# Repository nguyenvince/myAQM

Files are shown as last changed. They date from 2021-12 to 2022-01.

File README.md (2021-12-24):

# myAQM - A Personal Air Quality Monitor with Apple Watch Interface
This is the source code and documentation for **myAQM**, a personal air quality monitor (AQM) system that consists of a portable monitor that transmits measurements to an iOS/watchOS application user interface. This source code includes:
### 1. [Portable air quality monitor (completed)](/Portable%20air%20quality%20monitor)
- Fabrication guide (Refer to README.md)
- Arduino project
- Hardware fabrication files (3D-print and custom PCB files)
  
### 2. iOS/watchOS application (currently under-development)
XCode project

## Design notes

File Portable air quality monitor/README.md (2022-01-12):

# Open-source portable air quality monitor
```
Topics covered:  
Arduino IDE, ESP32, BLE, 3D-printing, PCB-fabricating 
```
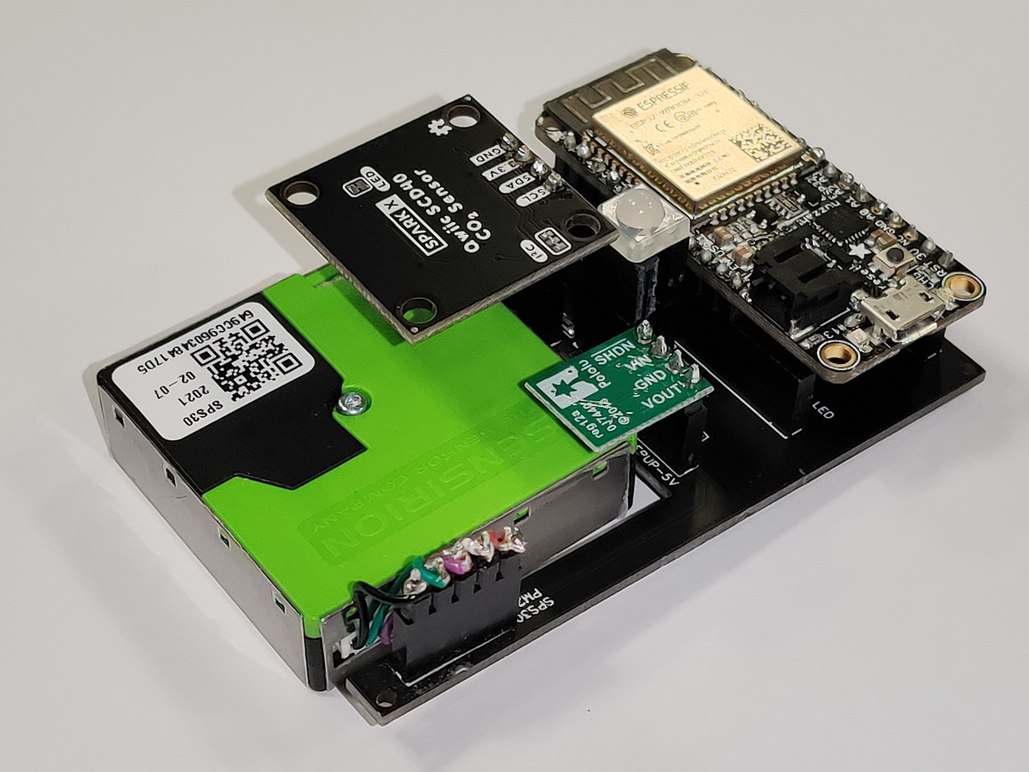
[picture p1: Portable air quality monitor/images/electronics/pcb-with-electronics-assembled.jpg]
Portable air quality monitor myAQM banner


## Table of contents
#### [1. Overview](#1-overview-1)
#### [2. Hardware specifications](#2-hardware-specifications-1)
#### [3. Hardware fabrication](#3-hardware-fabrication-1)
#### [4. Software implementation](#4-software-implementation-1)

#### Summary of important links
[Electronic components](#summary-of-hardware-components)
  
[PCB design (EasyEDA)](https://oshwlab.com/vtn238/portable-air-quality-monitor_copy_copy/)
  
[Enclosure design (Fusion 360)](/enclosure-design-fusion-360)

## 1. Overview
This documentation details the specifications and steps necessary to build **myAQM**, a  portable personal air quality monitor **(AQM)** that can be interfaced with an iOS/watchOS application.
  
<p align="center">
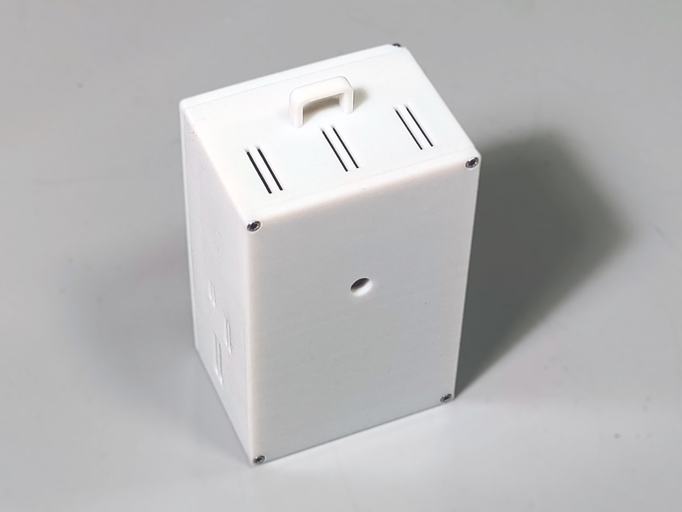
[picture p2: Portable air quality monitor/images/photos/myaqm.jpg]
A photo of myAQM - a personal portable air quality monitor
  
</p>

**myAQM** was designed with the following properties in mind:
### 1.1. User experience:
- **Monitoring a comprehensive set of indoor/outdoor air quality markers**
    - Particulate matter < 2.5μm (PM2.5)
    - CO2 carbon dioxide
    - Thermal comfort: temperature and humidity
- **Portable**
    - Light weight (174 gram)
    - Full-day battery life, multiple-day if [further optimized](#46-implementing-low-power-usage-to-prolong-battery-life)
    - Can be carried around on a backbag or other personal items with a hook / clip
- **Communicating with an iOS/watchOS app through Bluetooth Low-Energy (BLE)**
    - BLE comsumes less power than Wi-Fi
    - Allows for continuous data monitoring with the iOS/watchOS app no matter where the users go (as opposed to the limit range and accessibility of Wi-Fi networks)
- **High-fidelity prototype: functionally and aesthetically polished**
    - Custom-made PCB design
    - Custom-made 3D-printed enclosure
### 1.2. Developer experience:
- **Minimal form factor and easy fabrication**
    - Minimal number of components, most components are in breakout boards for easy fabrication and debugging 
    - Minimalistic and modular design which means electronic components can be re-used, re-purposed, or swapped out if broken
- **Open-source**
    - While **myAQM** was designed to be interfaced with Apple devices (iOS/watchOS) and used on-the-go, its hardware and source-code can be re-purposed for different monitoring setups (Wi-Fi connection, stationary station...)
  
## 2. Hardware specifications
**myAQM** hardware broadly consists of:
- A microcontroller (Adafruit ESP32)
- Environmental sensors
- Other electronic components
- Custom PCB, 3D enclosure, and some M1.6 x 6mm nuts
  
The choice for each of these components is discussed below, with unaffiliated links for purchase.
  
<p align="center">
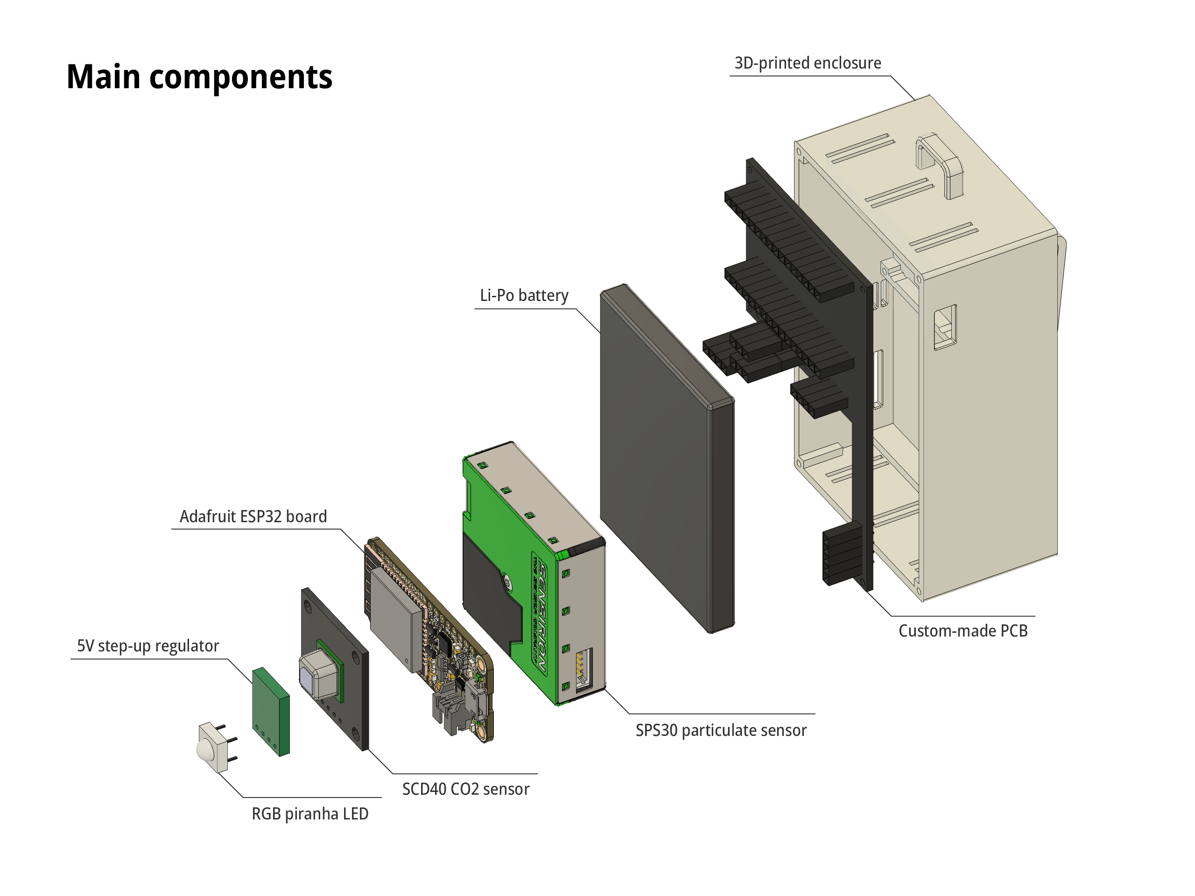
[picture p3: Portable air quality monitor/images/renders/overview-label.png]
myAQM overview of main components
  
</p>
  
### Summary of hardware components
| Jump to section | Description | Price* | Link
| --- | --- | --- | --- |
| [Adafruit ESP32](#21-adafruit-esp32-microcontroller) | Microcontroller with BLE | $19.95 | [Adafruit](https://www.adafruit.com/product/3405) |
| [Sensirion SPS30](#sensirion-sps30-particulate-matter) | Compact low-cost optical particulate matter sensor | $46.95 | [SparkFun](https://www.sparkfun.com/products/15103) |
| [Sensirion SCD40](#sensirion-scd40-co2-temp-and-humid) | Photoacoustic CO2 sensor, with temp and humid sensor | $49.95 | [SparkFun](https://www.sparkfun.com/products/18365) |
| [Pololu U1V11F5](#pololu-5v-step-up-voltage-regulator-u1v11f5) | 5V step-up voltage regulator for SPS30 | $6.95 | [Pololu](https://www.pololu.com/product/2562) |
| [Adafruit Diffused Piranha LED (pack of 10)] | Air quality index indicator | $0.995/cnt | [Adafruit](https://www.adafruit.com/product/1451) |
| [LilyPad Slide Switch](#onoff-switch) | On/off switch | $1.85 | [SparkFun](https://www.sparkfun.com/products/9350) |
| [2500mAh Li-Po Battery](#li-po-battery) | Rechargeable battery | $14.95 | [Adafruit](https://www.adafruit.com/product/328) |
| **Total** | (excluding consumables and fabrication cost) | $142 |  |
```
_*Price and availability as of Dec 2021_
```
### Schematics
  
<p align="center">
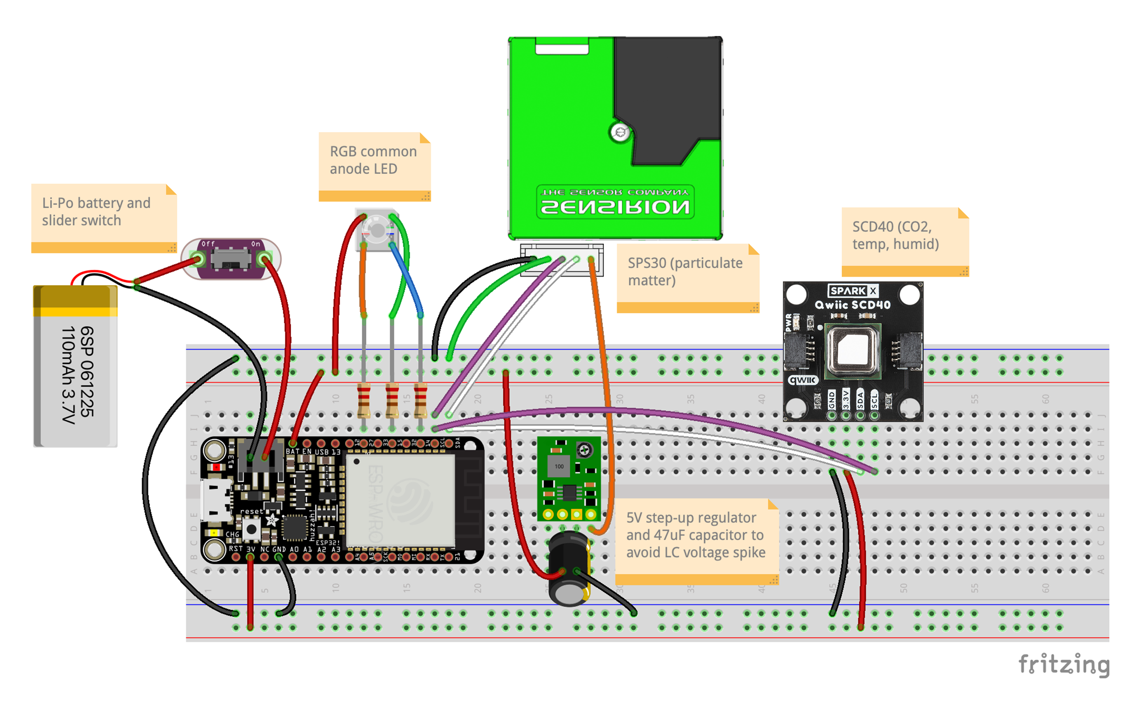
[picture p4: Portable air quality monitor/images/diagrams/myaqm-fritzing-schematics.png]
Fritzing schematic of the electronic components of myAQM
  
</p>
  
### 2.1. Adafruit ESP32 microcontroller
<p align="center">
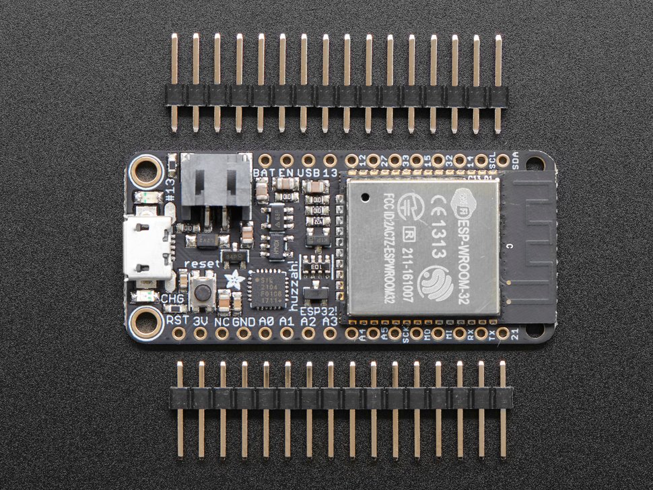
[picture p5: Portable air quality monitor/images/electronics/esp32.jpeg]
Adafruit ESP32 microcontroller
  
</p>
  
Adafruit ESP32 Feather Board microcontroller was chosen for the portable air quality monitor for its:
- Support of different wireless communication protocols: WiFi and Bluetooth Low-Energy (BLE)
- Intergrated battery charger and circuit protection (compared to the vanilla ESP32)
- Easy integration with the Arduino IDE platform

### 2.2. Environmental sensors
#### Sensirion SPS30 (particulate matter)
<p align="center">
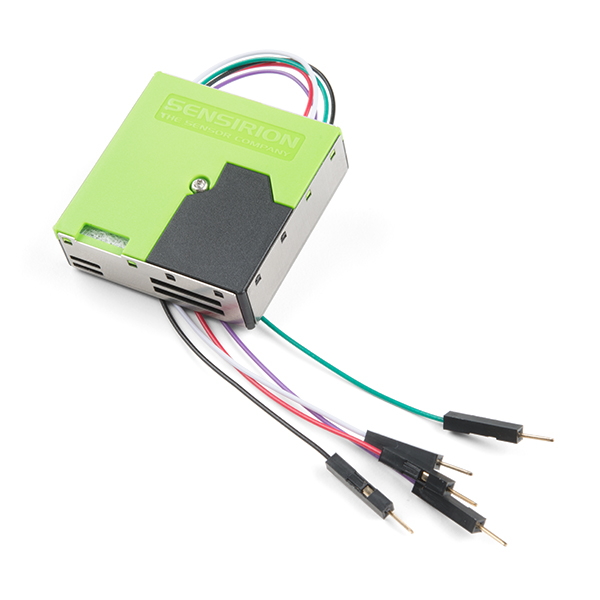
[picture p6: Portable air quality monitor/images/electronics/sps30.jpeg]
Sensirion SPS30 particulate matter
  
</p>
  
**Why measuring particulate mattter?**
  
Air pollution is the 4th leading factor for premature death, claiming over 6 million lives worldwide in 2019<sup>[1]</sup>. Microscopic particulate matter smaller than 2.5 micrometers (PM2.5) is among the most hazardous forms of outdoor and indoor air pollution. PM2.5 particles can penetrate and lodge into our lungs and internal organs<sup>[2]</sup>, causing respiratory and cardiovascular diseases. It is estimated that more than 90% of the world population live in areas where annual PM2.5 concentrations exceed the guildlines put forth by the World's Heath Organization (WHO)<sup>[1]</sup>.
  
Sensirion SPS30 particulate matter sensor is chosen for its relative accuracy among other similar low-cost optical sensors and for its compactness for this highly-portable monitor. Research has indicated a good correlation between SPS30's measurements with those from reference instruments<sup>[3], [4]</sup> It comes with both I2C and UART communication protocols, which makes it extremely versatile for any application. We'll use I2C in this case.

#### Pololu 5V Step-Up Voltage Regulator U1V11F5
<p align="center">
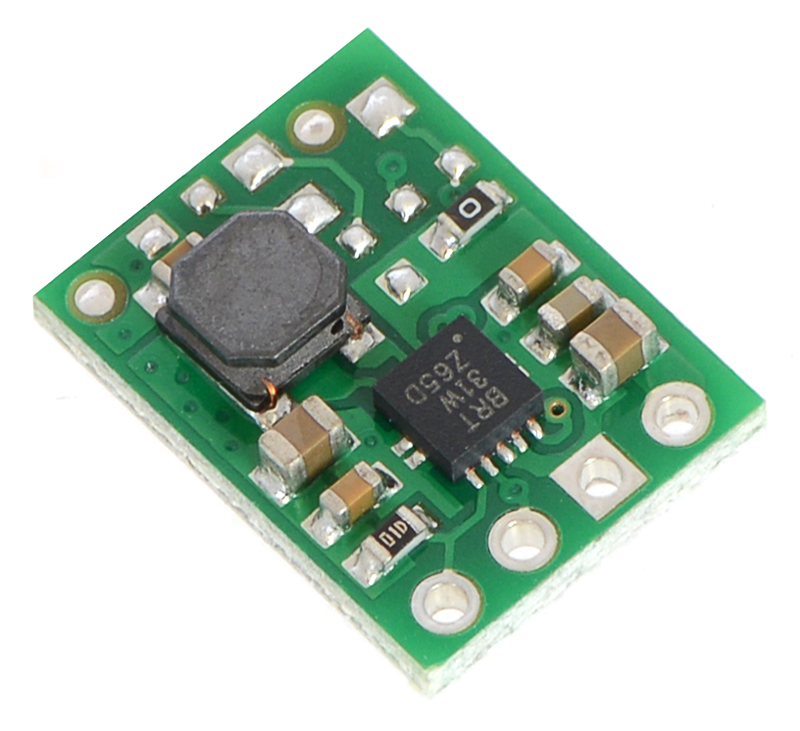
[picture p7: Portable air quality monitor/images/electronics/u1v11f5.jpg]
Pololu 5V Step-Up Voltage Regulator U1V11F5
  
</p>
This voltage regulator is used to step up the 3.7V nominal output (3.4V - 4.2V experimentally) from the Li-Po battery to 5V required to power up the SPS30 sensor. It is chosen for its small size and conversion efficiency.

#### Sensirion SCD40 (CO2, temp, and humid)
<p align="center">
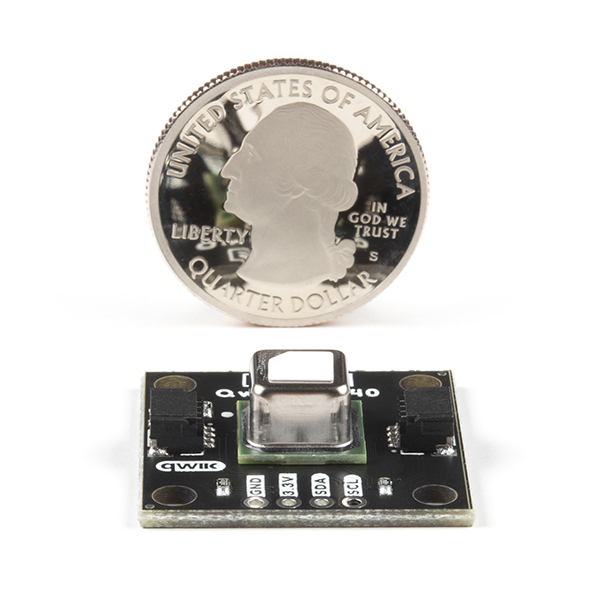
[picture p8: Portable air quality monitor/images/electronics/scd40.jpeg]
Sensirion SCD40 C02, temp, and humid
  
</p>
  
**Why measuring CO2?**
  
CO2 concentration is a powerful indicator of indoor air quality as it is a by-product of human respiration process. Exposure to high indoor CO2 concentrations (>1000ppm, new research even indidates at >600-700ppm) have been linked with a reduction in cognitive performance<sup>[5],[6]</sup>. High indoor CO2 levels indicate low fresh air intake which increases the risk of airborne diseases (such as COVID-19) in highly-pollutated indoor environment<sup>[7]</sup>. Low indoor ventilation also results in the build-up of other harmful pollutants such as votatile organic compounds (VOCs), radons, molds, and so on.
  
This Sensirion SCD40 CO2 sensor employs break-through technology in photoacoustic sensing. It is considerably smaller and more energy-efficient than a typical NDIR (nondispersive infrared) sensor ([See SCD30](https://www.sensirion.com/en/environmental-sensors/carbon-dioxide-sensors/carbon-dioxide-sensors-scd30/)). Due to its recent debut in 2021, the SparkFun breakout board is currently an experimental product; however, it works particularly well from our experience.
  
The sensor also comes equipped with a temprature and humidity sensor, which eliminates the need for a separate sensor, making the system more streamlined.
  
The sensor uses I2C protocol.

### 2.3. Other electronic components
#### Li-Po battery
<p align="center">
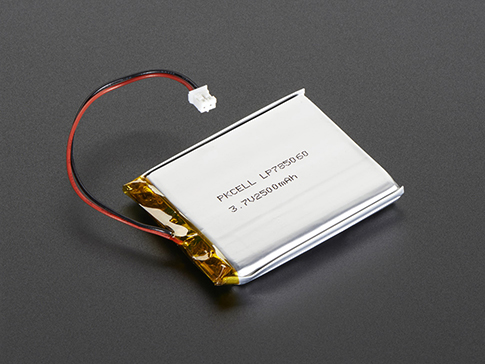
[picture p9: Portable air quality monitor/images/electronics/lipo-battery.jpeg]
2500mAh Li-Po Battery
  
</p>
This high capacity 2500mAh Li-Po battery from Adafruit can be connected directly to the Adafruit ESP32 board. It is also equipped with circuitry protection for our peace of mind. It can be recharged using the built-in circuit on the Adafruit ESP32 with any over-the-counter microUSB cable.
  
Alternatively, any other Li-Po battery can be used, provided it comes with a 2-pin JST PH connector.
  
The calibration of the battery (voltage to percentage) is discussed in section [4.5. Calibrating Li-Po battery](#45-calibrating-li-po-battery)
#### LED indicator
<p align="center">
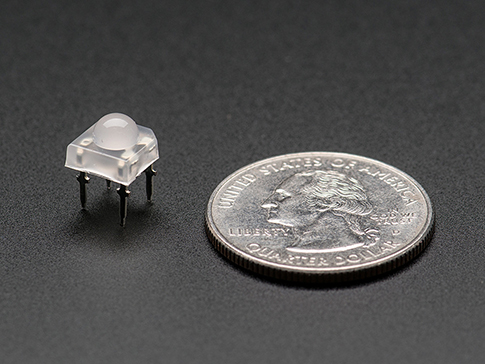
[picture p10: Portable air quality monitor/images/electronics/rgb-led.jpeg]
RGB LED Piranha
  
</p>
This RGB LED indicator is used to display current air quality index (using US AQI) for at-a-glance information. This feature can also be used when the portable air quality monitor is not connected with an iOS/watchOS app for us to read its measurements.
  
<p align="center">
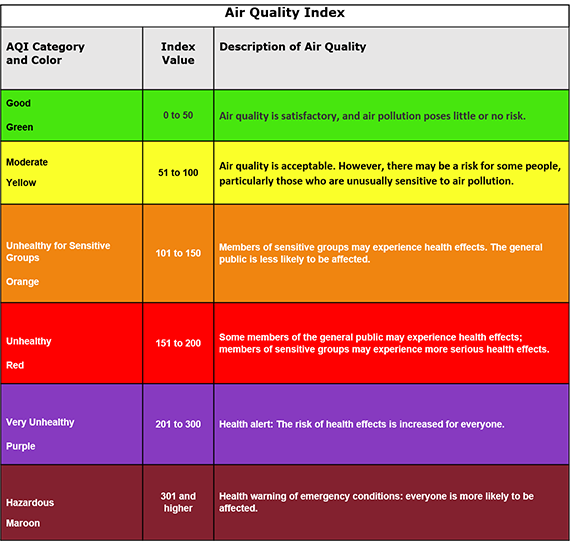
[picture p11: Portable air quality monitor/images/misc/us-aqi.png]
US Air quality index chart
  
</p>
  
**myAQM** does not come with a small LCD display on the air quality like other DIY monitors as it focuses on the visualization of the data on the iOS/watchOS app. However, users are encouraged to tailor the open-source design to their preferences.

#### On/off switch
<p align="center">
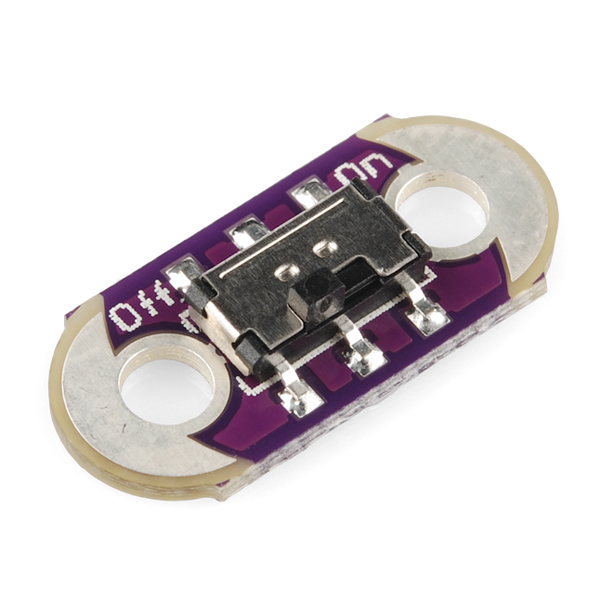
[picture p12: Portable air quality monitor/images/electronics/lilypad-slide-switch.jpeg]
Lilypad Slider Switch
  
</p>
  
This component is quite self-explainatory.
  
## 3. Hardware fabrication
### 3.1. Custom PCB
**myAQM** is designed with the motherboard-daughterboards philosophy:
- It allows for easy plug-and-play of the various breakout boards that we purchase from Adafruit/SparkFun...
- It allows for quick debugging during prototyping and re-use/re-purpose after the prototyping process of such breakout components. For example, if the CO2 sensor fails, another one can be swapped in with little effort.
- All while achieving a highly-polished and durable MVP that is not achievable if using breadboards or protoboards
  
<p align="center">
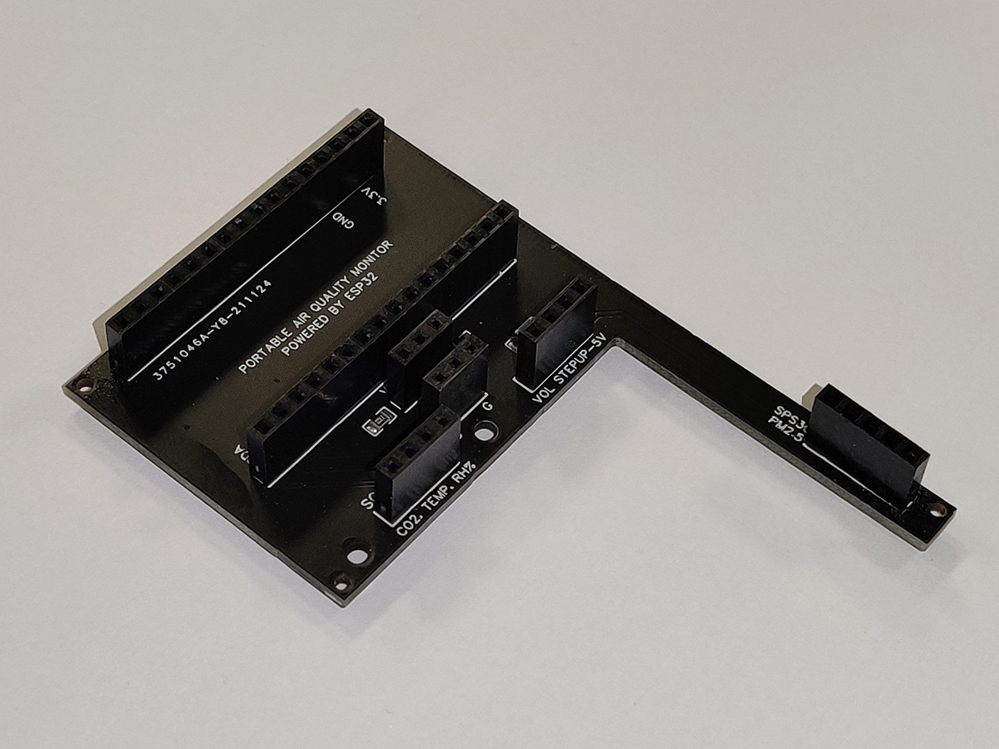
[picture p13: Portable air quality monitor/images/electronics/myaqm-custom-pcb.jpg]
Custom PCB photo
  
</p>

The custom PCB is designed using **EasyEDA**, an online editor with functionalities similar to other CAD software. The design is sent to **JLC PCB** (Shenzhen, China) for fabrication. The advantages of this approach is its fast turn-over time for quick prototyping; surface-mounted components (resistors, capacitors) and through-hole components (female recepticles) can be selected from EasyEDA and are automatically soldered on the PCB boards by JLC, which eliminates the need for additional soldering.
  
[Here](https://oshwlab.com/vtn238/portable-air-quality-monitor_copy_copy/) is the link to all the files and parts needed to construct the PCB with EasyEDA and JLC PCB.
  
#### Below is an overview of the PCB design process:
  
A graphic schematic for all the electronic components is laid out:
  
<p align="center">
  Fritzing schematic of the electronic components of myAQM
</p>
  
We then design a corresponding schematic on EasyEDA, with most of the components swapped out for female recepticle parts (which can be found on [JLC PCB](https://jlcpcb.com/parts)):
  
<p align="center">
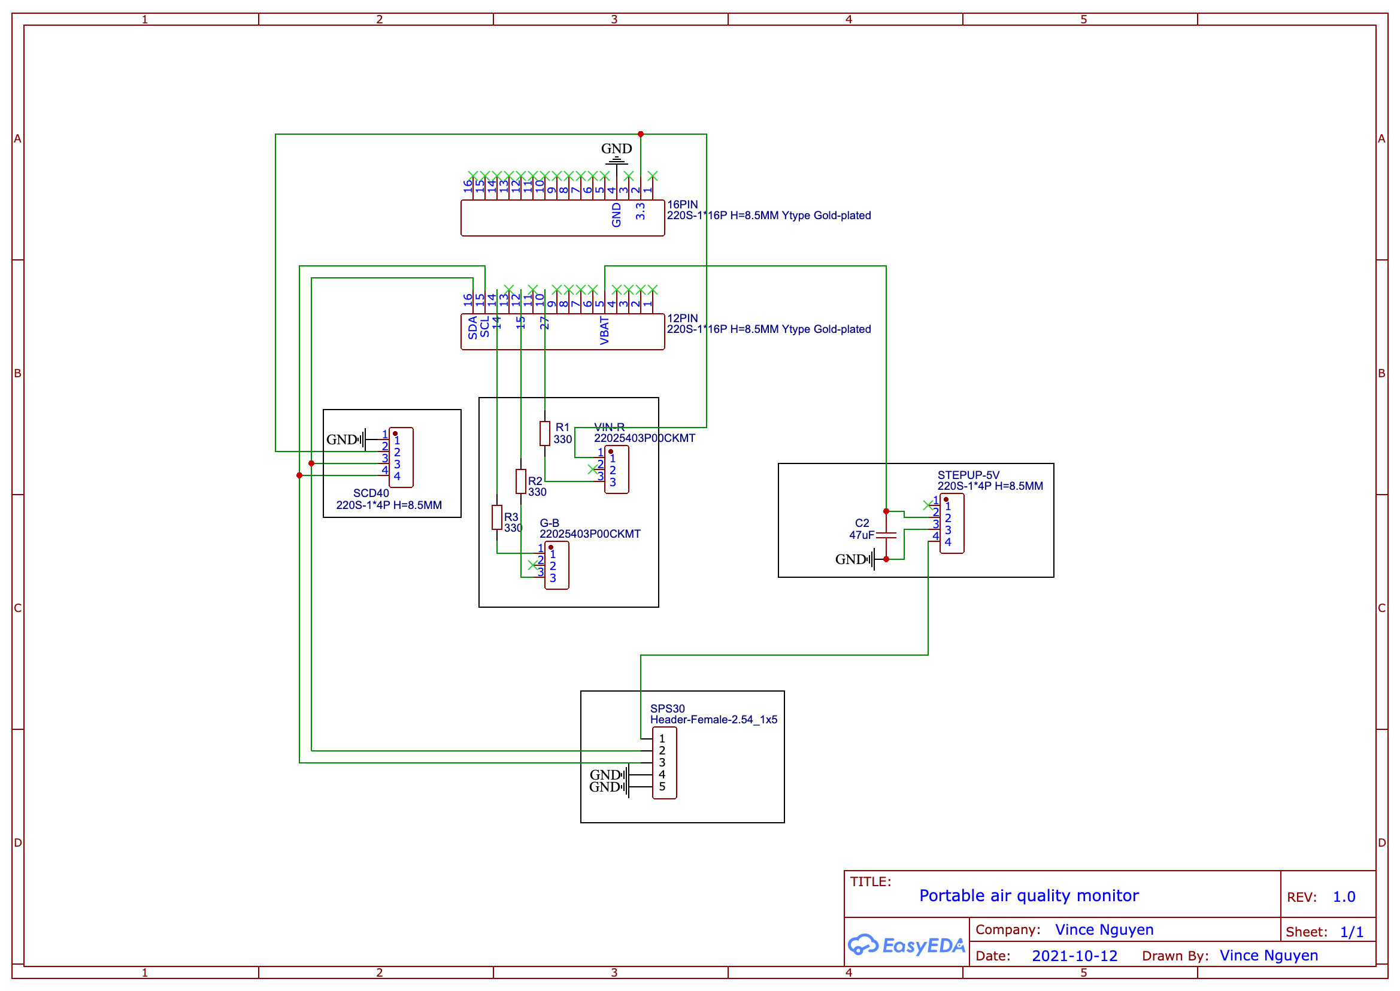
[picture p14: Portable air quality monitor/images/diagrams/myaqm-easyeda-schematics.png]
Custom PCB designed in EasyEDA
  
</p>
  
In addition to the female recepticles that will connect to the electronic components, there are three `330Ω` resistors to limit the current going though the RGB LED (one for each color) and a `47μF` capacitor close to the voltage regulator (between `VIN` - `GND`)to prevent LC voltage spikes. The final design is a 2-layered simple PCB.
  
<p align="center">
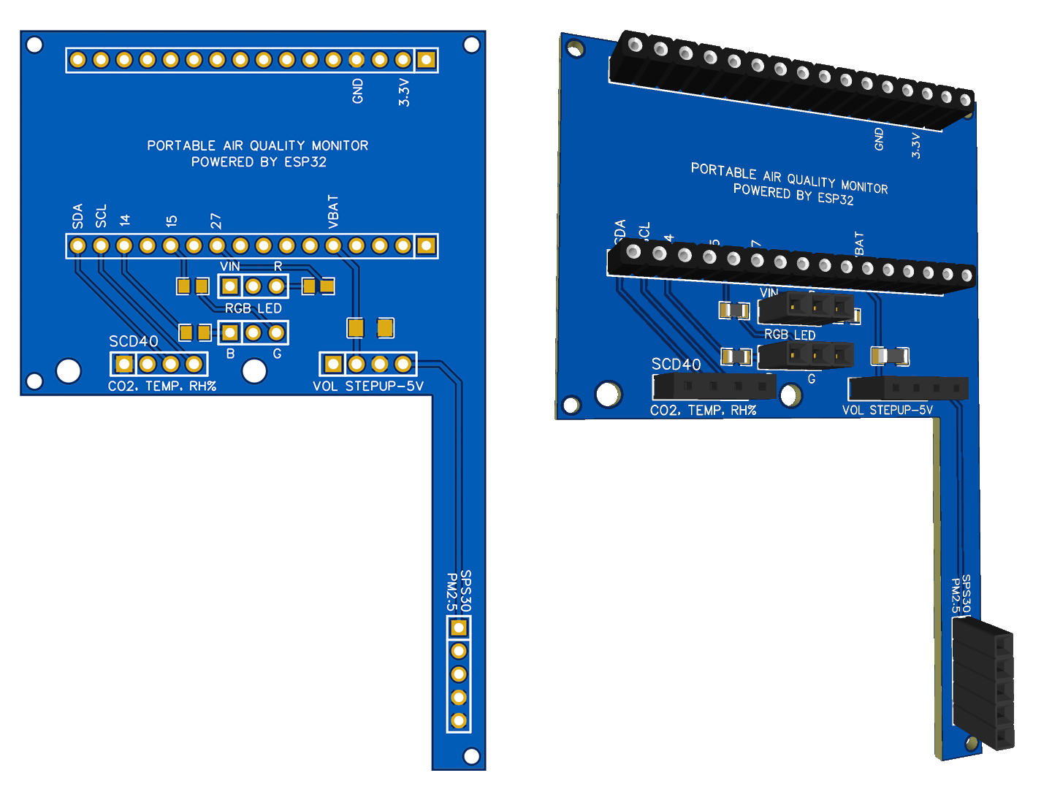
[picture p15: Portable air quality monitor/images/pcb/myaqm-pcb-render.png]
2D and 3D renders of the PCB
  
</p>
  
*2D and 3D renders of the PCB with SMT components and female recepticles soldered in place*
  
### 3.2. Custom 3D-printed enclosure
The enclosure is designed in **Fusion 360**. The Fusion 360 project can be found [here](), in case any modification is needed. As it features some complicated features, SLA printing was used to ensure maximum accuracy.
  
<p align="center">
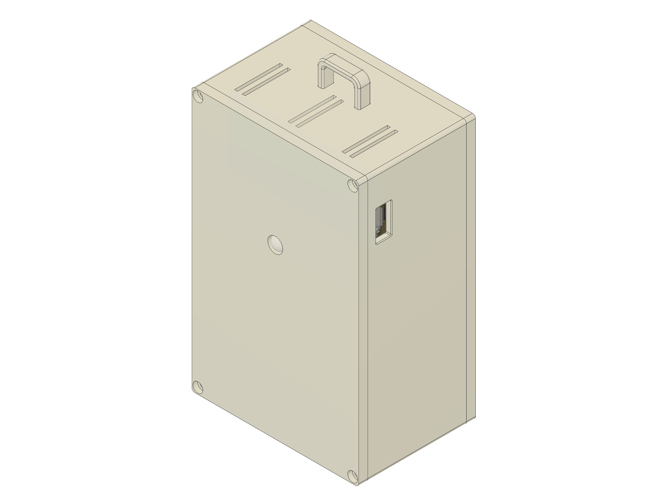
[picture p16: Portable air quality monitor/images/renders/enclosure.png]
Render of the enclosure
  
  <br/><i>3D render of the enclosure</i>
</p>

<p align="center">
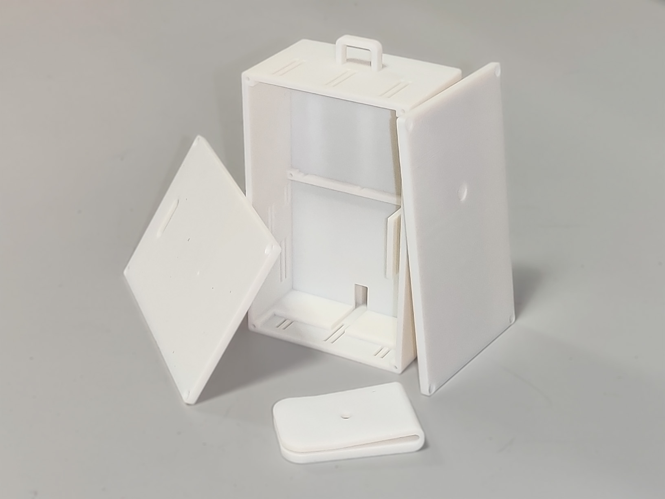
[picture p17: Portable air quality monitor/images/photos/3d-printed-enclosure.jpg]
3D printed enclosure photo
  
  <br/><i>All the components of the enlcosure after 3D printed</i>
</p>
  
#### Some design choices:
  
<p align="center">
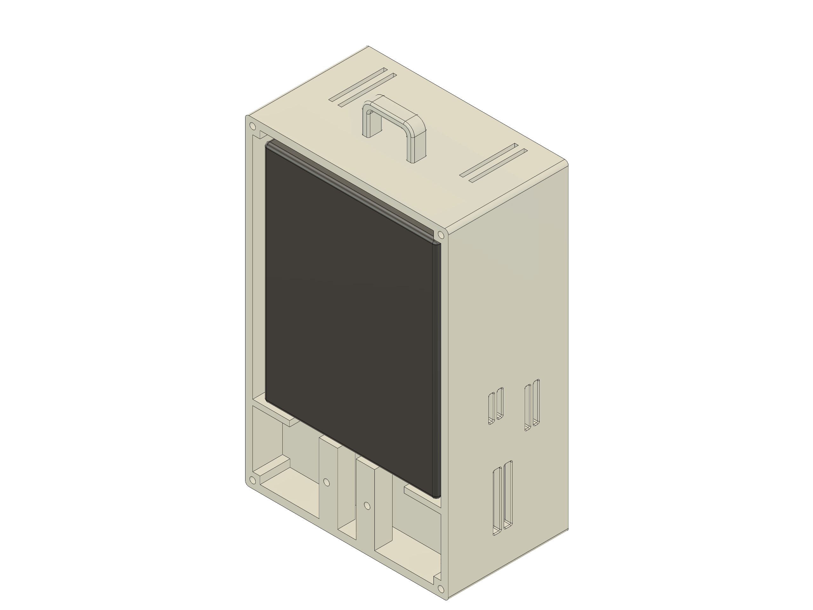
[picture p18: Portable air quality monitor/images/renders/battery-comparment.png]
Render of battery compartment
  
    <br/><i>The battery is placed in a separate partition to avoid overheating other components</i>
</p>
  
<br/>
  
<p align="center">
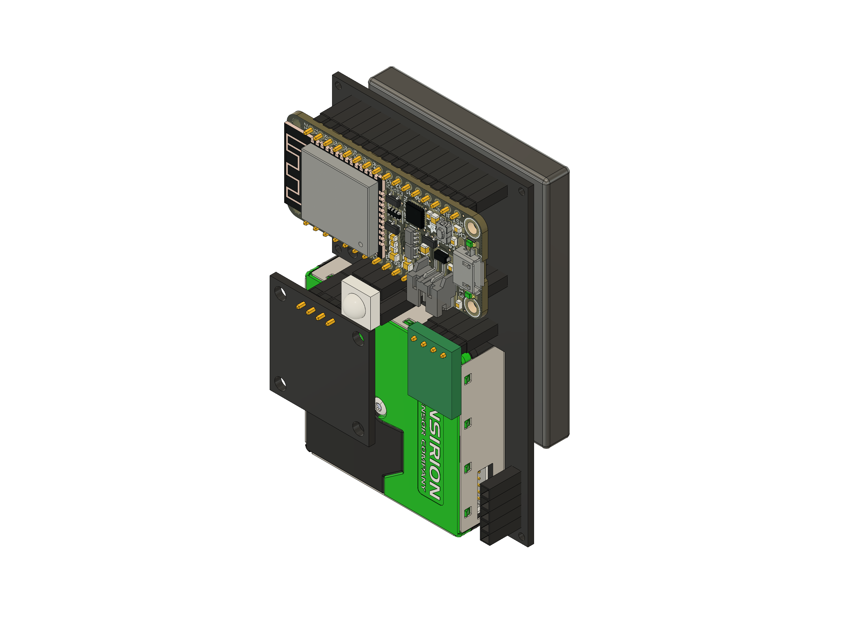
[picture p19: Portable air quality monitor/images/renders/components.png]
Render of ESP32 placement relative to the PCB
  
  <br/><i>Similarly, the ESP32 board is placed at the highest position (as heat rises)</i>
</p>
  
<br/>
  
<p align="center">
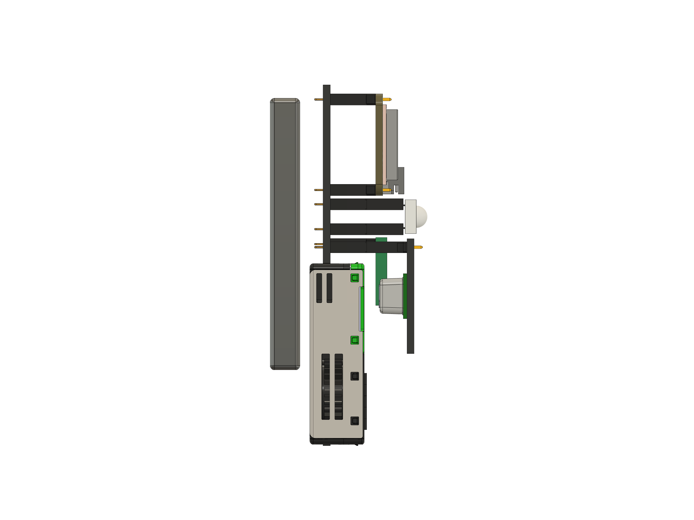
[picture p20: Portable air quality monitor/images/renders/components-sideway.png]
Render of SPS30 placement relative to the PCB
  
  <br/><i>The SPS30 is positioned such that "Inlets should always be above outlet to avoid particles getting back from the outlet to the inlets due to gravity" - <a href="misc/PS_AN_SPS30_Mechanical_Design_and_Assembly_Guidelines_v10_D2.pdf">Mechanical Design and Assembly Guidelines for SPS30</a></i>
</p>
  
<br/>
  
<p align="center">
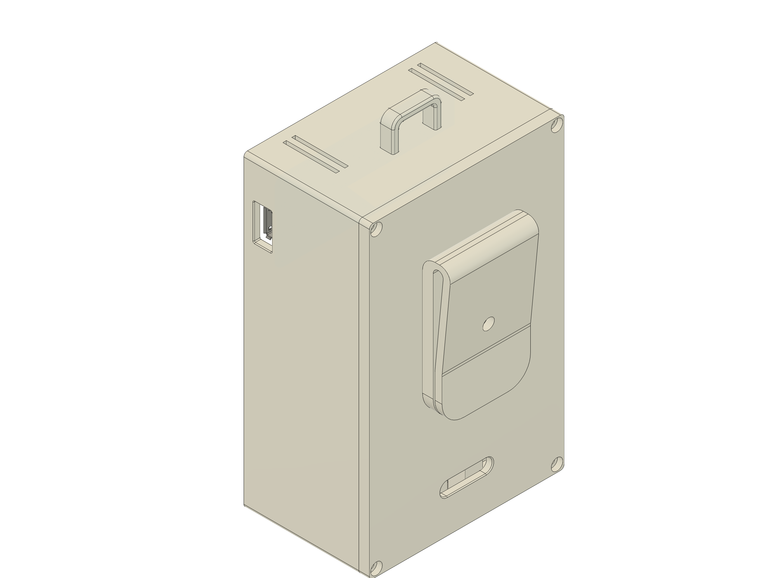
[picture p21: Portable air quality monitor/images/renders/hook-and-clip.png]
Render of the hook on top and the clip on the back
  
  <br/><i>A hook is added on top of the enclosure. A clip is added on the back of the enclosure. Both of which can be used to attach the portable air quality monitor to the users' backpack, belts, or any other personal items that they often carry around during a typical day</i>
</p>
  
<br/>
  
<p align="center">
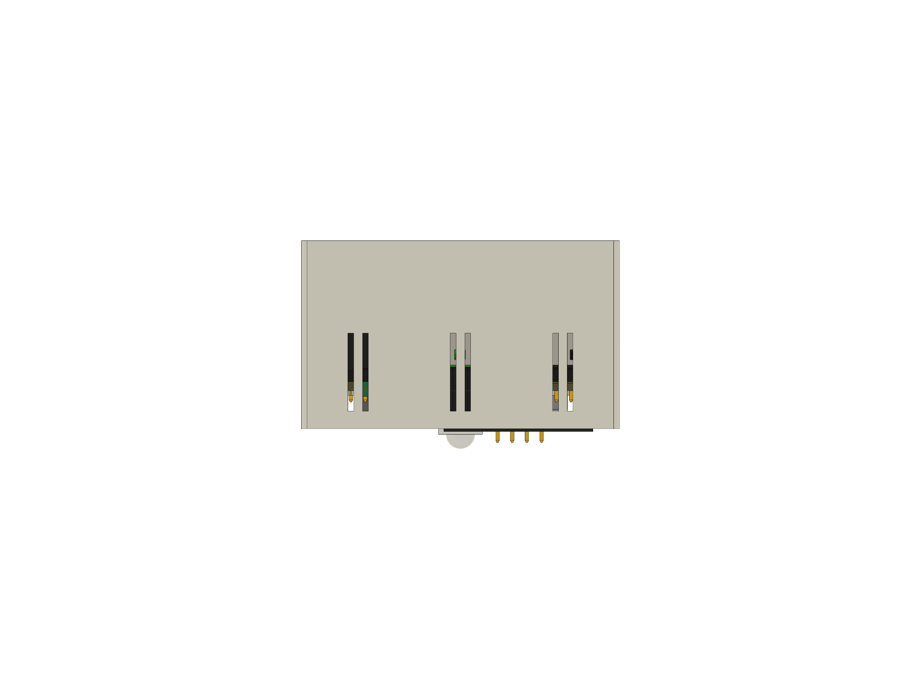
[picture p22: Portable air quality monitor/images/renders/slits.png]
Render of the slits for ventilation
  
    <br/><i>Some perforated slits to supply fresh air</i>
</p>
  
<br/>
  
<p align="center">
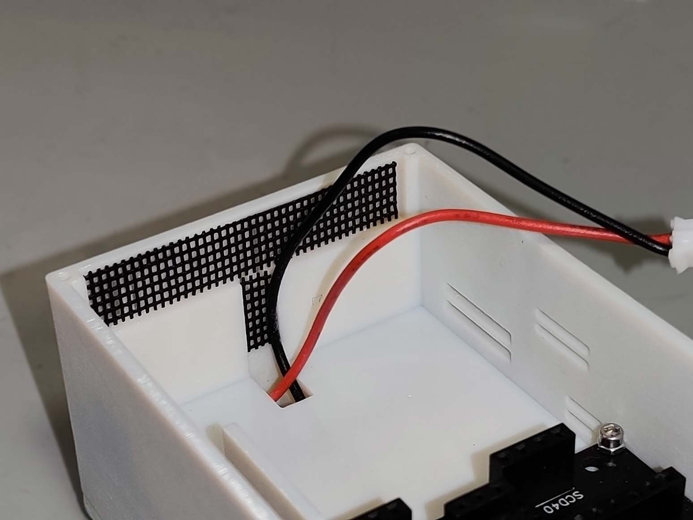
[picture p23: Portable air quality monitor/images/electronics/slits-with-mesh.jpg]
Photo of the slits for ventilation, fitted with some plastic mesh to prevent dust from getting inside
  
<br/><i>Optionally, some plastic mesh can be used to cover the slits to avoid big debris/dust particles to enter the interior</i>
</p>
  
### 3.3. Putting everything together
As explained before, the design objective of the portable air quality monitor is modular and reusable. The PCB board already comes installed with the female recepticles; therefore, we only need to solder male pin headers (2.54mm/0.1in) into *most* of the sensors:
  
<p align="center">
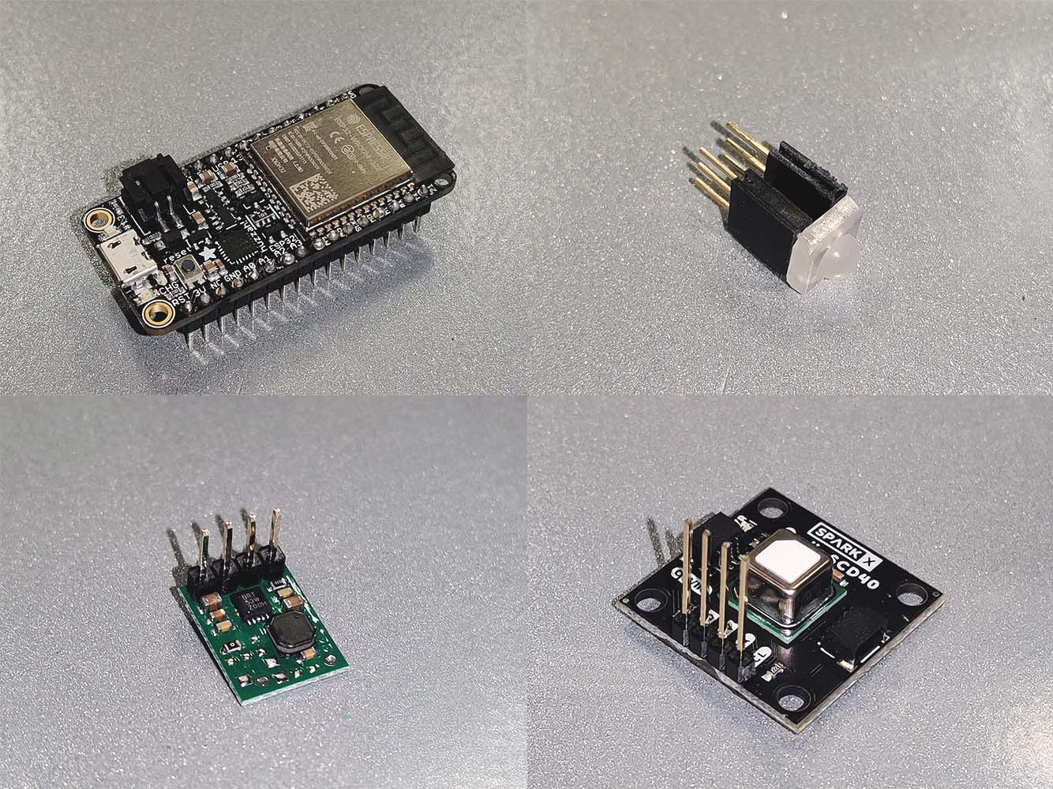
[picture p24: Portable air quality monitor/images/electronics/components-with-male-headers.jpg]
Components with the male headers soldered on
  
  <br/><i>ESP32, RGB LED, Pololu 5V Step-up voltage regulator, and SCD40 CO2 sensor (left to right, top to bottom). The SCD40 sensor must be soldered into a [LONG (TALL) male header](https://www.sparkfun.com/products/10158) to create enough clearance between itself and the SPS30 sensor fitted underneath.</i>
</p>
  
<br/>
  
Meanwhile, the SPS30 particulate matter sensor purchased from SparkFun comes with a JST-ZHR Cable - 5-pin x 1.5mm Pitch to Breadboard connector (spare can be found [here](https://www.sparkfun.com/products/15108)). As a work-around, for our PCB board, we trim the 5 wires and solder them into a male header so that they can be plugged into the corresponding female recepticles:
  
<p align="center">
  SPS30 sensor with its connector wires soldered into a male header
</p>
  
<br/>
  
The RGB LED is connected to another set of female recepticles before being connected to the recepticles soldered on the PCB. The reason is to brings it closer to the front cover of the enclosure. This is how the board looks like after everything is plugged into:
  
<p align="center">
  PCB with all electronic components plugged in
</p>
  
<br/>
  
The red (positive) wire of the Li-Po battery is then soldered into the switch like such:
  
<p align="center">
  Battery with slider switch
</p>
  
<br/>
  
The slider switch can then be mounted onto the back of the 3D-printed enclosure with two M1.6 x 6mm nuts. The battery is then placed in the back compartmemt. The back compartment is designed to be bigger than the nominal size of the battery so that the battery has some room to expand. A cushioned mesh can be added to fill in the space between the battery and the back panel:
  
<p align="center">
  Battery with slider switch mounted on the back of the enclosure, with the battery in the back compartment, and some cushioned mesh to allow the battery to expand
</p>
  
<br/>
  
Next, the 3D-printed clip can be held secured onto the back panel with a pair of M1.6 nuts and bolts. The back panel can then be mounted with four additional M1.6 nuts:
  
<p align="center">
  The clip secured onto the back panel
</p>
    
<br/>
  
The back panel can be mounted in the main body, with four M1.6 x 6mm nuts at each corner:
  
<p align="center">
  View from the back panel of the portable air quality monitor
</p>
  
<br/>
  
After finishing the back of the portable air quality, we turn to assemble the front. First, the motherboard PCB can be secured onto the front of the 3D-printed enclosure with four M1.6 x 6mm nuts:
  
<p align="center">
  PCB mounted on the front of the enclosure
</p>
    
<br/>
  
The rest of the electronics can then be added, with the SPS30 sensor fits snuggly in its own comparment like such: 
  
<p align="center">
  SPS30 in the enclosure
</p>
  
<br/>
  
Afterwards, the front cover can be mounted:

<p align="center">
  View from the front panel of the portable air quality monitor
</p>
  
<br/>
  
Optionally, a ring hook can be attached like below:
  
Ring hook on top of the enclosure
  
## 4. Software implementation
The entire Arduino project of the portable air quality monitor can be found [here](https://github.com/myAQM/myAQM/arduino-code).

Before the project can be flashed to the ESP32, the [ESP32 Platform](https://docs.espressif.com/projects/arduino-esp32/en/latest/installing.html) should be added to the Arduino IDE and [drivers for Adafruit ESP32](https://learn.adafruit.com/adafruit-huzzah32-esp32-feather/using-with-arduino-ide) should be installed.

This documentation assumes a basic working knowledge of the Arduino IDE platform.
  
### 4.1. Software overview
Flow chart of the software
  
### 4.2. Getting data from the sensors
Two Arduino libraries are used to get measurements from SPS30 and SCD40:
- [SparkFun SCD4x Arduino Library](https://github.com/sparkfun/SparkFun_SCD4x_Arduino_Library)
- [Arduino library for Sensirion SPS30](https://github.com/Sensirion/arduino-sps)
Methods to return the measurements are encapsulated in `.cpp` and `.h`. The methods are quite straight-forward as they are pulled directly from respective Arduino libraries for those Sensirion sensors.
### 4.3. Implementing BLE connection
>For tutorial on [Bluetooth Low-Energy on ESP32](https://randomnerdtutorials.com/esp32-bluetooth-low-energy-ble-arduino-ide/)

The table below summarizes the BLE services and their BLE characteristics with UUIDs that **myAQM** advertises:
  
<table>
    <thead>
        <tr>
            <th>BLE Services (UUIDs)</th>
            <th>BLE Characteristics (UUIDs)</th>
            <th>Properties</th>
        </tr>
    </thead>
    <tbody>
        <tr>
            <td rowspan=4><a href="#431-environmental-sensing-service"><b>Environmental Sensing service</b></a> (0x181A)</td>
            <td>Particulate Matter PM2.5 characteristic (0x2BD6)</td>
            <td>READ, NOTIFY</td>
        </tr>
        <tr>
            <td>Carbon Dioxide CO2 characteristic (0x2BD6)*</td>
            <td>READ, NOTIFY</td>
        </tr>
        <tr>
          <td>Temperature characteristic (0x2A6E)</td> 
            <td>READ, NOTIFY</td>
        </tr>
        <tr>
            <td>Humidity characteristic (0x2A6F)</td>
            <td>READ, NOTIFY</td>
        </tr>
        <tr>
            <td rowspan=2><a href="#432-metadata-service"><b>Metadata service</b></a> (0x9999)**</td>
            <td>Status characteristic (0x9998)**</td>
            <td>READ, NOTIFY</td>
        </tr>
        <tr>
            <td>Timestamp (UNIX) characteristic (0x9997)**</td>
            <td>READ, WRITE, NOTIFY</td>
        </tr>
        <tr>
            <td><a href="#433-battery-service"><b>Battery service</b></a>  (0x180F)</td>
            <td>Battery Level characteristic (0x2A19)</td>
            <td>READ, NOTIFY</td>
        </tr>
    </tbody>
</table>
  
```
* Technically, this is Carbon Monoxide's UUID because CO2 doesn't have a standardized characteristic UUID
  
** Custom UUIDs
```
  
#### 4.3.1. Environmental Sensing service
This BLE service contains 4 BLE characteristics that describes the air quality data:
- Particulate matter PM2.5 (μg/m<sup>3</sup>)
- Carbon dioxide CO2 (ppm)
- Temperature (C)
- Humidity (%)
#### 4.3.2. Metadata service
This custom BLE service contains 2 BLE characteristics:
- **Status**: this contains a single number string to describe the timing nature of the BLE notifications that are sent to the iOS/watchOS app
  - `STATUS_REGULAR "1"`: when BLE notifications are sent as part of the regular interval `NOTIFY_CHARAC_INTERVAL` (default `10 minute`). This will be the primary status of connection between **myAQM** and the paired iOS/watchOS app.
  - `STATUS_URGENT "2"`: when BLE notifications are sent because of a significant change in air quality. This is to promptly inform users of real-time short-burst pollution event, before the intended regular interval. This is discussed more in-depth in [4.3.4. Timeframe of BLE Events](##434-timeframe-of-ble-events).
  - `STATUS_HISTORY "3"`: when BLE notifications are sent as part of a BLE re-connection with the paired iOS device following a temporary disconnection from **myAQM**. The data being sent are past measurements that did not have the chance to be pushed over to the iOS device. This is discussed more in-depth in [4.4. Implementing SPIFFS data storage](#44-implementing-spiffs-data-storage).
    
- **Timestamp (UNIX)**: `epochTime` will be initialized during the first connection after power-on with the iOS app (with real-time data from the app). This will be used to keep track of the UNIX time of past measurements. This will only be used during historical data notifications following a BLE re-connection `STATUS_HISTORY "3"`. During real-time notifications `STATUS_REGULAR "1"` and `STATUS_URGENT "2"`, Timestamp is not sent to save bandwidth; instead, it will be obtained directly on the iOS application side.
#### 4.3.3. Battery service
This BLE service contains one single BLE characteristic: Battery Level characteristic.
#### 4.3.4. Timeframe of BLE Events
Being a portable device, **myAQM** has to balance between power consumption and measurement response time. This proves to be crucial when choosing a good time interval to update the BLE characteristics and notify the iOS/watchOS app. While continuous measurement and data logging via BLE connection will instantaneously notify users of short-burst pollution event, this will severely undermine the battery life of not just the device itself but also the paired iOS/watchOS device. Therefore, **myAQM** uses multiple time intervals to determine if new measurements should be retrieved and/or notified to the iOS/watchOS app, from most frequently to least frequently excecuted:
  
<p align="center">
  View from the front panel of the portable air quality monitor
</p>
  
1. Every `MEASUREMENT_INTERVAL` (default `30s`), new readings from sensors are retrieved. The measurements are then kept track to calculate running average to smooth out noises.
2. Every `UPDATE_CHARAC_INTERVAL` (default `60s`), the running average of the latest `UPDATE_CHARAC_INTERVAL / MEASUREMENT_INTERVAL`entries are calculated and the BLE characteristics are updated. This is the **real-time air quality reading**; however, the iOS/watchOS app will not be notified unless there is a **significant change** in air quality (either degradation or improvement). A **significant change** is defined as a change from one air quality index (AQI) category to another AQI category of this running average compared to the running average over the previous `NOTIFY_CHARAC_INTERVAL`. Notifcations sent here have a STATUS characteristic of `STATUS_URGENT "2"`.
3. Every `NOTIFY_CHARAC_INTERVAL` (default `10min`), the measurements' running average is calculated and sent to the iOS/watchOS app to keep it up-to-date. Notifcations sent here have a STATUS characteristic of `STATUS_REGULAR "1"`.
  
This algorithm is able to moderately preserve battery life and yield near real-time air quality measurements while promptly notify users of short-burst pollution events. It will also ensure users can access real-time air quality data if they want to (by requesting from the app interface), instead of having to wait for 10 minutes for the automatic notification from the BLE device.
  
All of the 3 time intervals are customizable in `configs.h`; however, `MEASUREMENT_INTERVAL` should be a multiple of 30 seconds if low-power mode is used on the SCD40 sensor (discussed [here](#46-implementing-low-power-usage-to-prolong-battery-life)). Additionally, this relationship between the 3 time intervals must be satisfied:
```
NOTIFY_CHARAC_INTERVAL = m * UPDATE_CHARAC_INTERVAL = n * MEASUREMENT_INTERVAL
  
where m, n are integers > 1
```
### 4.4. Implementing SPIFFS data storage
>For tutorial on [SPIFFS](https://randomnerdtutorials.com/install-esp32-filesystem-uploader-arduino-ide/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,like%20the%20ESP32%20flash%20memory.)
  
For use cases where the portable air quality monitor is not connected to the iOS/watchOS app, we need to store data locally and opportunistically upload the logged data once a reconnection is established. One solution is to use a microSD card breakout board. However, to avoid complicating the prototype at this point, we decide to use the internal memory onboard the ESP32 microcontroller instead.
  
The onboard permanent memory is called SPIFFS, and it has 1MB memory of storage. While this might seem abysmal, it is worth noted that a record only consumes some tens of bytes. 1MB is more than enough for days of continuous logging before a re-connection is established. After all, this is only intended for when there is no connection with the phone app and not for long term storage, which will be handled by the iOS/watchOS app.
  
Data will only be logged locally if a connection has been established at least once since device power, due to the fact that only then will the AQM receive datetime data from the iOS/watchOS app. Without this crucial datetime data, it has no way of knowing the real time stamp of the historical measurements (Timestamp BLE characteristic discussed earlier in [4.3.2. Metadata service](#432-metadata-service)).
  
Functions to deal with SPIFFS tasks are located in the `aq-monitor.ino` file as they did not work when being encapsulated in a seperate header file. The 4 functions are:
- `void setup_SPIFFS()`: Initialize the SPIFFS partition, format the SPIFFS if the initialization fails (this can be deactivated via the variable `FORMAT_SPIFFS_IF_FAILED` in the `configs.h` file). To be called in the `void setup()` function in the `aq-monitor.ino` file.
- `void deleteFile(fs::FS &fs, const char * path)`: Remove the temporary data file after finishing uploading the data to the iOS/watchOS app to free up space.
- `void appendFile(fs::FS &fs, const char * path, const char * message)`: Append new measurement to `FILENAME` (can be changed in `configs.h`). This function takes the message to be appended as a `char` array.
- `void readFileToUpdateBleCharacteristics(fs::FS &fs, const char * path)`: Read the data file line by line to upload the data via BLE to iOS/watchOS app.

### 4.5. Calibrating Li-Po battery
<p align="center">
  The corner of the device lights up while charging
  <br/><i>The corner of **myAQM** lights up while charging</i>
</p>

Since Li-Po batteries exhibit a non-linear relationship between voltage vs. charge, it is necessary to calibrate them to roughly extrapolate battery percentage from voltage measurement taken from ESP32. On [Adafruit ESP32 documentation](https://learn.adafruit.com/adafruit-huzzah32-esp32-feather/power-management), the battery voltage ADC pin is the A13 (35 for Arduino code).
  
>Since the ESP32 has tons of ADC pins, we 'sacrifice' one for Lipoly battery monitoring. You can read half of the battery voltage off of A13. Don't forget to double the voltage you read, since there is a divider.
  
The calibration process is done by letting the whole system run continuously from full-charge to battery dead, which lasts ~16 hours during our early prototyping phrase. Every hour, we measure simultaneously the true voltage (with a multimeter between BAT and GND pin) and the calculated voltage from ADC pin. The calibration process for this 2500mAh Li-Po battery involves two steps:
#### 4.5.1. Converting calculated voltage from ADC pin to true voltage
Battery voltage from ADC reading can be calculated with this formula:
```
CALCULATED_VOL = (ADC_READING / 4095) * 3.3V * 2
```  
where **ADC_READING** is the analog measurement from A13 pin. This has to be divided by 4095 since ESP32 is a 10-bit system, then multiplied by 3.3V since ESP32 operating voltage is 3.3V, then doubled as stated in the ESP32 documentation.
  
However, this value does not necessarily reflects the true voltage measured with a multimeter due to ADC attenuation. To fix this issue, we plot true measured voltage vs. calculated voltage (from ADC pin) and plotted this linear regression chart for a conversion formula:
  
<p align="center">
  Measured true voltage vs. Calculated voltage from ADC pin plot
</p>
  
#### 4.5.2. Converting true voltage to percentage level
With the true voltage (which ranges from 3.4V to 4.2V), we now proceed to correlate the battery voltages to the battery percentages. To approximate the battery percentage consumed over each hour, we divided 100% by the number of hours that the system lasts until battery dead, assuming the power consumption stays relatively constant throughout the process. We then plot this 3<sup>rd</sup> degree polynomial regression chart, which gives an excellent R<sup>2</sup> value:
  
<p align="center">
  True voltage vs. Battery percentage plot
</p>

Solving for battery percentage at any given voltage then, however, requires us to solve this 3<sup>rd</sup> degree polynomial equation on the fly, which is notoriously complicated:
```
y = ax^3 + bx^2 + cx + d
```
where y is the true voltage and x is the battery percentage we are interested in.
  
Due to energy saving and calculation power concern, we decide to calculate in advance a 5%-increment look-up table for the conversion instead and save this in the Arduino sketch:
| True voltage (V) | Battery percentage |
| --- | --- |
| 4.183 | 1.00 |
| 4.104 | 0.95 |
| 4.034 | 0.90 |
| ... | ... |
| 3.476 | 0.10 |
| 3.437 | 0.05 |
| 3.393  | 0.00 |
```
// Look-up table array for battery percentage from true battery voltage
// 5% increment
// #define BATTERY_LEVELS_NUM 21
const float battery_levels[BATTERY_LEVELS_NUM] = {
4.183, 4.104, 4.034, 3.972,
3.917, 3.869, 3.826, 3.788, 
3.754, 3.724, 3.696, 3.670,
3.645, 3.621, 3.596, 3.570,
3.541, 3.510, 3.476, 3.437, 3.393
};
```
We assume a 5% increment look-up table should achieve a good memory usage while still giving users enough high-resolution data on the battery level.
#### Remark:
If a different battery model is used, this two-step battery calibration must be carried out again.
### 4.6. Implementing low-power usage to prolong battery life
The 2500mAh battery in **myAQM** lasts for more than **40 hours** of continuous usage (paired with iOS app) thanks some minor adjustments below:
- Underclocking the CPU: by default, the dual-core CPU runs on 240Mhz with the Arduino IDE. However, with a single line of code `setCpuFrequencyMhz(80)`, we can easily cut it in third. This results in a reduction of around **20-30mA** in supply current.  
- Using low-power mode for the SCD40 CO2 sensor: `scd40.startLowPowerPeriodicMeasurement()`. In this mode, the sensor returns one measurement every 30 second, instead of 5 second in normal mode. This cuts supply current from 15mA to 3mA.
- Implementing intermittent measurement for the SPS30 sensor: In this mode, the sensor first runs for 30 seconds to obtain a valid reading, then idles for another 30 seconds. One complete measurement cycle is therefore 1 minute. This cuts supply current in half, from 55mA to 23mA. Refer to [Low-Power Operation Of the SPS30 Particulate Matter Sensor](misc/Sensirion_Particulate_Matter_AppNotes_SPS30_Low_Power_Operation_D1.pdf) for further optimization.
  
While more aggressive solutions, such as ESP32 deep sleep and/or BLE sleep, can further increase the battery life, for our objective of a full-day battery life, the aforementioned measures suffice. A potential problem of turning on and off BlE is an increase in power consumption of the iOS/watchOS due to frequent scanning for the BLE peripheral device; thus, it was not explored in this iteration of the prototype.
  
### 4.7. (Alternative) Implementing WiFi connection with ThingSpeak server
As mentioned, ESP32 is a powerful microcontroller with BLE and Wi-Fi capabilities. For any application that requires Wi-Fi as the sole/hybrid mode of communication, one can easily integrate ThingSpeak IoT platform to **myAQM** without having to set up one's own server nor database. Tutorials can be found on [Mathworks](https://www.mathworks.com/help/thingspeak/measure-arduino-wifi-signal-strength-with-esp32.html) and [RandomNerdTutorials](https://randomnerdtutorials.com/esp32-thingspeak-publish-arduino/). We are not going to discuss the actual technical implementation here; however, the only modification to the source code would be to substitute the BLE code with the Wi-Fi and ThingSpeak code, all else stay the same.
  
---
## Reference
1. State of Global Air 2020. Special Report. Boston, MA: Health Effects Institute; 2020
2. Li, Donghai, et al. “Fluorescent Reconstitution on Deposition of PM2.5 in Lung and Extrapulmonary Organs.” *PNAS*, National Academy of Sciences, 12 Feb. 2019, [https://www.pnas.org/content/116/7/2488](https://www.pnas.org/content/116/7/2488)
3. Sousan, Sinan, et al. “Laboratory Evaluation of Low-Cost Optical Particle Counters for Environmental and Occupational Exposures.” *Sensors*, vol. 21, no. 12, 2021, p. 4146., [https://doi.org/10.3390/s21124146](https://doi.org/10.3390/s21124146). 
4. *Sensirion - SPS30 Eval Kit*, South Coast AQMD, [http://www.aqmd.gov/aq-spec/sensordetail/sensirion---sps30-eval-kit](http://www.aqmd.gov/aq-spec/sensordetail/sensirion---sps30-eval-kit)
5. 
6. 
7.

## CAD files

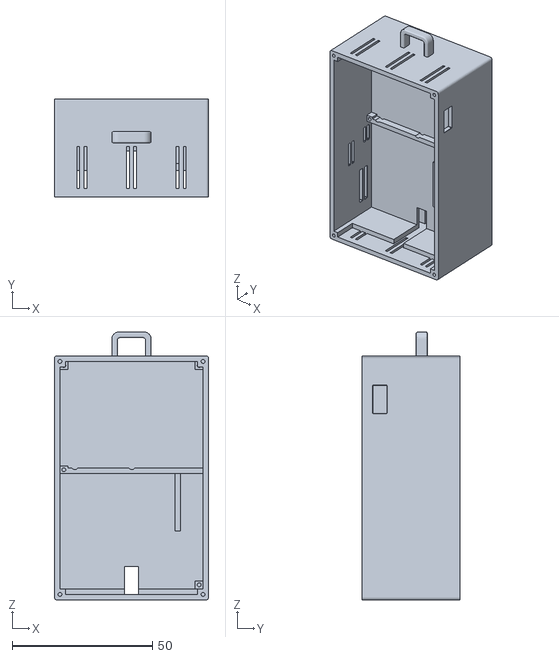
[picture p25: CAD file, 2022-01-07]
Portable air quality monitor/enclosure design/stl files/main_box.stl
55.0 x 35.0 x 95.5

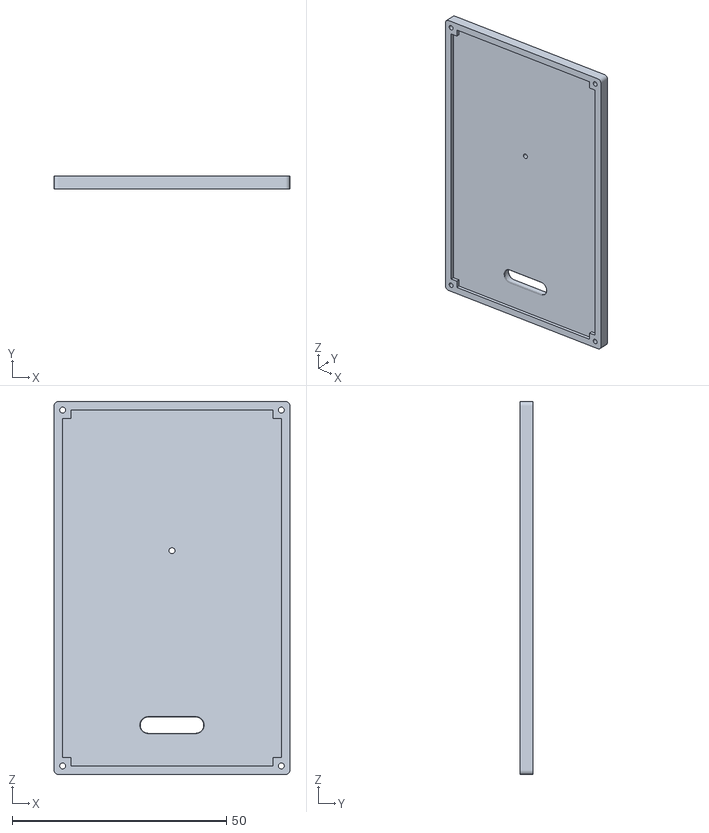
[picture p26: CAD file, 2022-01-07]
Portable air quality monitor/enclosure design/stl files/back_cover.stl
55.0 x 3.00 x 87.0

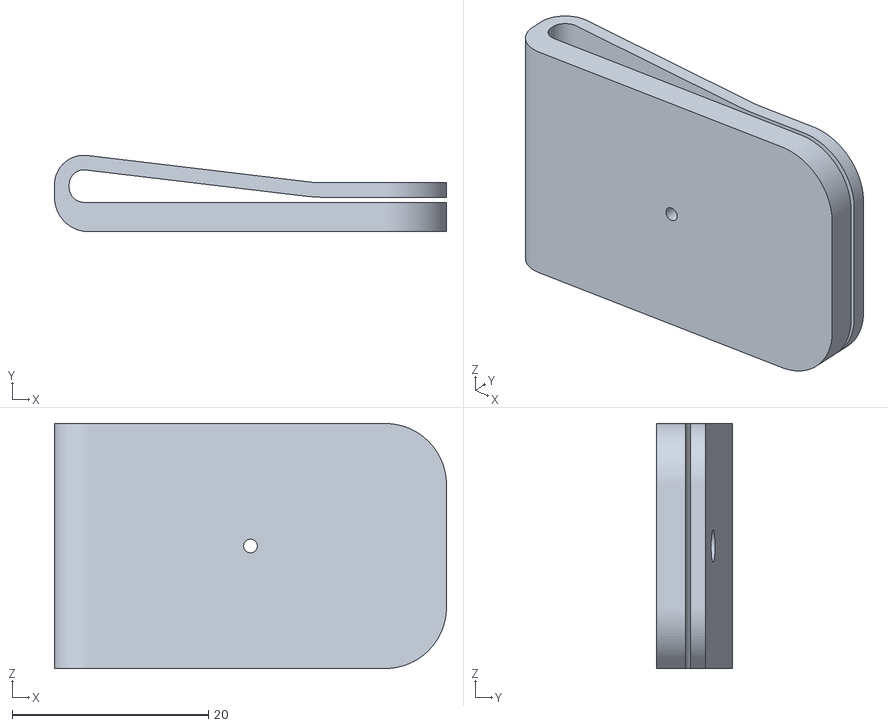
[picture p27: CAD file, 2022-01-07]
Portable air quality monitor/enclosure design/stl files/clip.stl
40.0 x 7.80 x 25.0

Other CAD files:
Portable air quality monitor/enclosure design/stl files/front_cover.stl

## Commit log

2021-12-29 added pcb photo
2022-01-06 added assemblage documentation
2022-01-07 enclosure design files
    [back_cover.stl, clip.stl, front_cover.stl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]
